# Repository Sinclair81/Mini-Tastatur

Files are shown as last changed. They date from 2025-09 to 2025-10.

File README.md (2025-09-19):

# Mini-Tastatur



<!-- markdownlint-disable MD033 -->
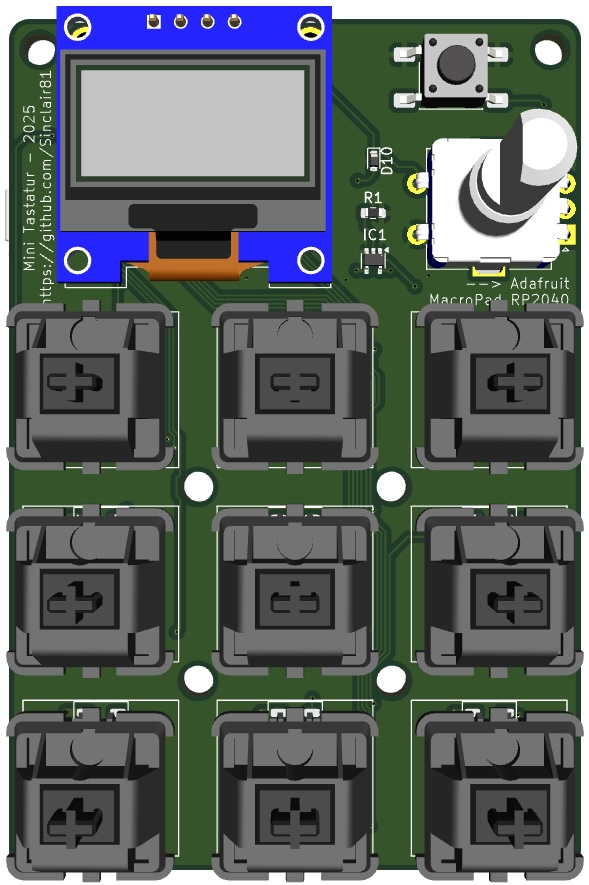
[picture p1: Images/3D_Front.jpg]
3D_Front

<!-- markdownlint-enable MD033 -->

A smal clone of the [Adafruit MacroPad RP2040](https://learn.adafruit.com/adafruit-macropad-rp2040).  

- Raspberry Pi Pico
- I2C Display
- 9 Buttons

[CircuitPython for Raspberry Pi Pico](https://circuitpython.org/board/raspberry_pi_pico)

[MacroPad CircuitPython Library](https://learn.adafruit.com/adafruit-macropad-rp2040/macropad-circuitpython-library)

Extract the zip and navigate to the lib folder found within. Drag the necessary libraries from the zip lib folder to the lib folder on your CIRCUITPY drive.

At a minimum, the following libraries are required to use the MacroPad CircuitPython library. Drag the following files and folders to the lib folder on your CIRCUITPY drive:

adafruit_macropad.mpy - A helper library for using the features of the Adafruit MacroPad.
adafruit_debouncer.mpy - A helper library for debouncing pins. Used to provide a debounced instance of the rotary encoder switch.
adafruit_simple_text_display.mpy - A helper library for easily displaying lines of text on a display.
neopixel.mpy - A CircuitPython driver for NeoPixel LEDs.
adafruit_display_text/ - A library to display text using displayio. Used for the text display functionality of the MacroPad library that allows you easily display lines of text on the built-in display.
adafruit_hid/ - CircuitPython USB HID drivers.
adafruit_midi/ - A CircuitPython helper for encoding/decoding MIDI packets over a MIDI or UART connection
adafruit_ticks.mpy - A helper to work with intervals and deadlines in milliseconds

There is an example included that uses a library that is not required for the MacroPad library to work, but provides a convenient way to layout text in grid. The following library is recommended as well:

adafruit_displayio_layout - A library that includes a grid layout helper.

[MacroPad Basics](https://learn.adafruit.com/adafruit-macropad-rp2040/macropad-basics)  

[MacroPad Display Text](https://learn.adafruit.com/adafruit-macropad-rp2040/macropad-display-text)  

[MacroPad Keyboard and Mouse](https://learn.adafruit.com/adafruit-macropad-rp2040/macropad-keyboard-and-mouse)  

[Arduino IDE Setup](https://learn.adafruit.com/adafruit-macropad-rp2040/arduino-ide-setup)  

[MacroPad Arduino Example](https://learn.adafruit.com/adafruit-macropad-rp2040/arduino)  

Name                  | Pin
--------------------- | ---------------------
Button / Boot select  | GPIO0 / TP6  
Button 1              | GPIO1  
Button 2              | GPIO2  
Button 3              | GPIO3  
Button 4              | GPIO4  
Button 5              | GPIO5  
Button 6              | GPIO6  
Button 7              | GPIO7  
Button 8              | GPIO8  
Button 9              | GPIO9  
Rotary Encoder A      | GPIO17  
Rotary Encoder B      | GPIO18  
Neopixel (9)          | GPIO19  
Display SDA           | GPIO20  
Display SCL           | GPIO21  
Reset                 | RUN

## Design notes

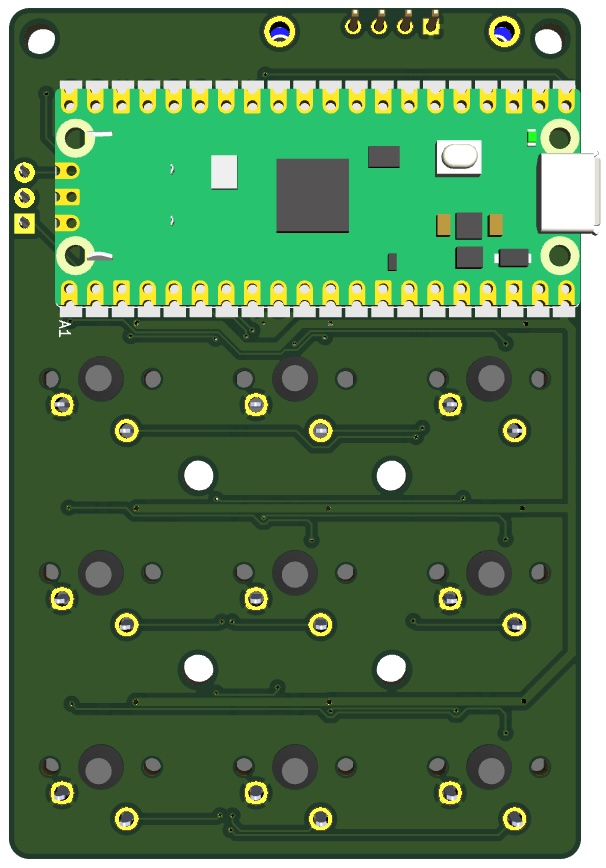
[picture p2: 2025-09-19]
Images/3D_Back.jpg

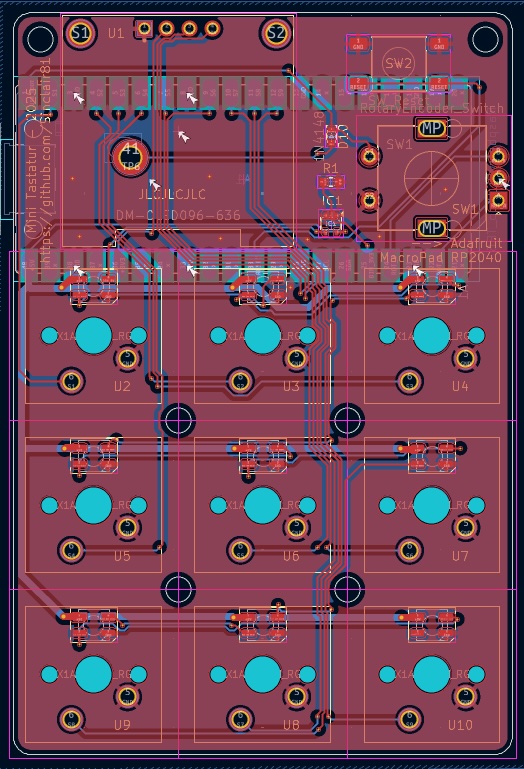
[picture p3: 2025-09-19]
Images/PCB_Front.jpg

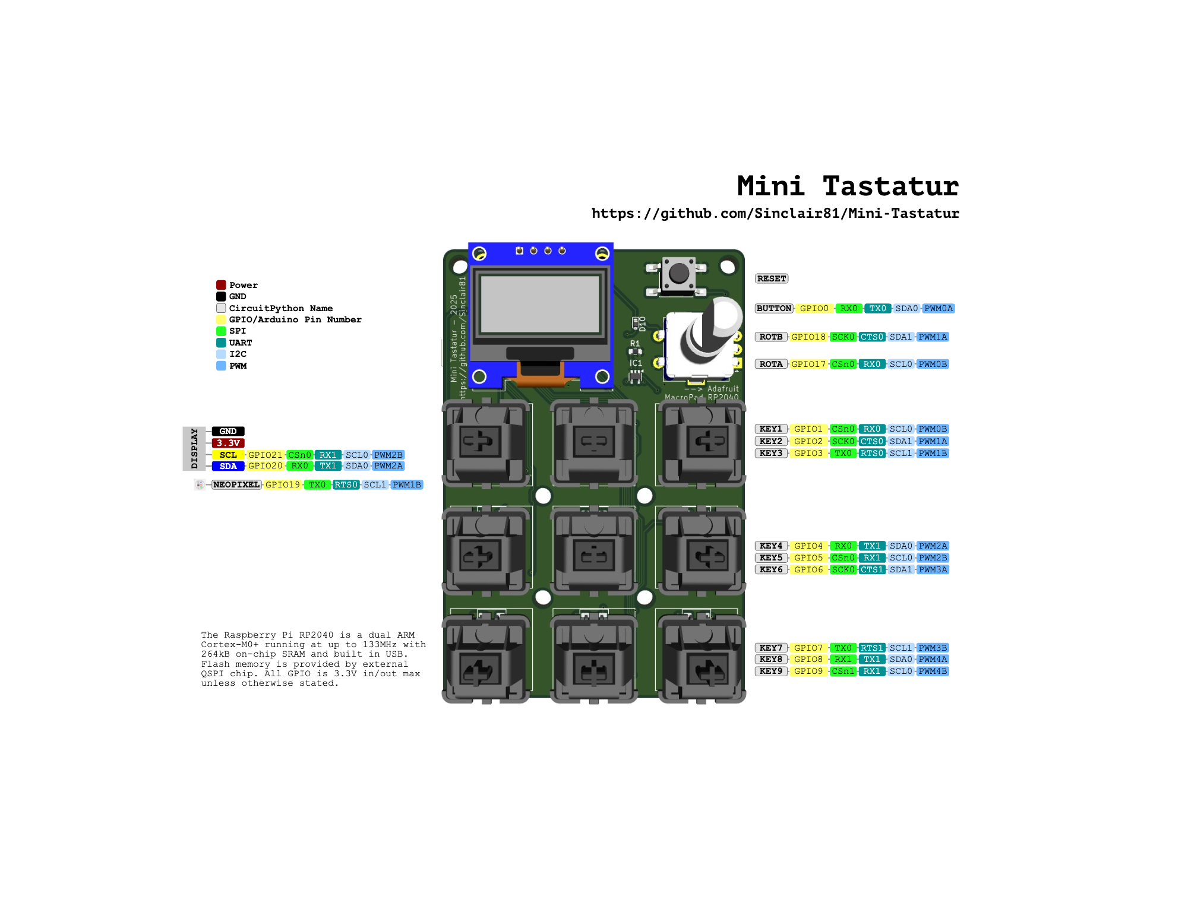
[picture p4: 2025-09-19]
Mini Tastatur Pins.png

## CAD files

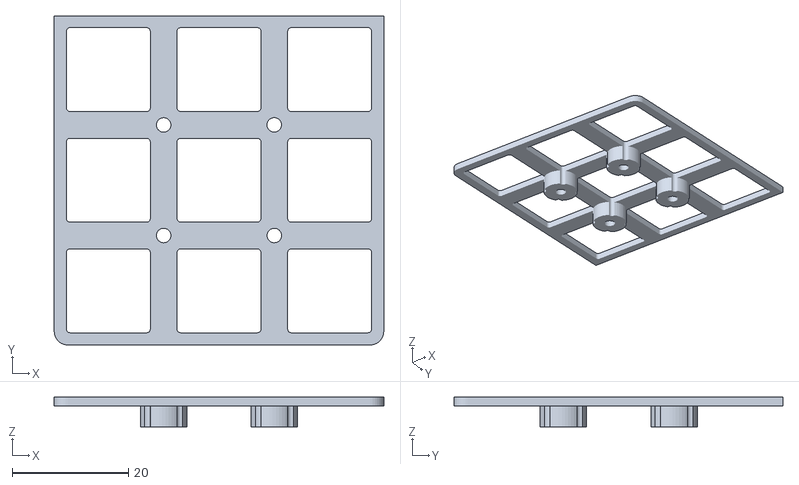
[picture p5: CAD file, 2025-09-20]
3D Print/Mini_Tastatur v14 Key holder.stl
56.6 x 56.5 x 5.10

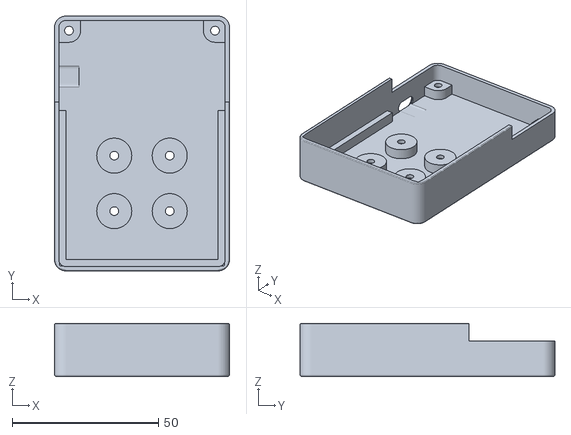
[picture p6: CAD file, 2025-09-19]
3D Print/Mini_Tastatur v14 housing bottom.stl
60.0 x 87.3 x 18.2

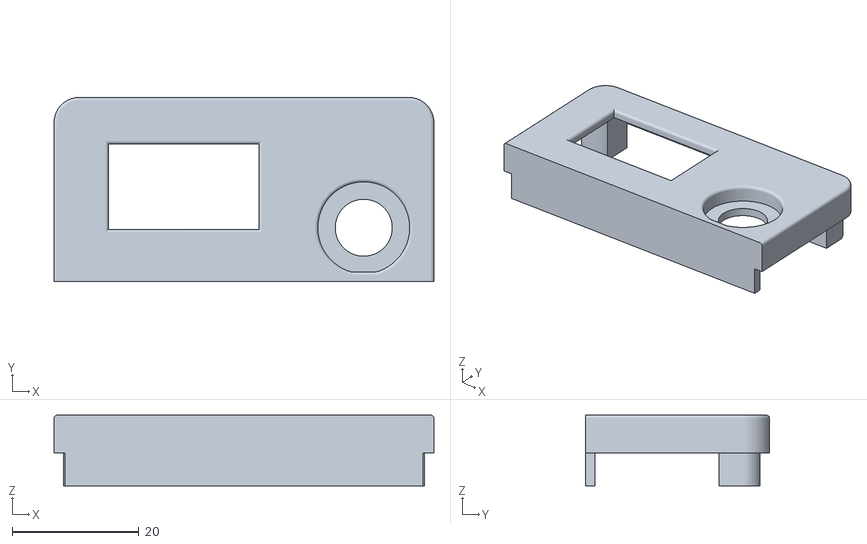
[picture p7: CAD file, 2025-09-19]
3D Print/Mini_Tastatur v14 housing top.stl
60.0 x 29.1 x 11.1

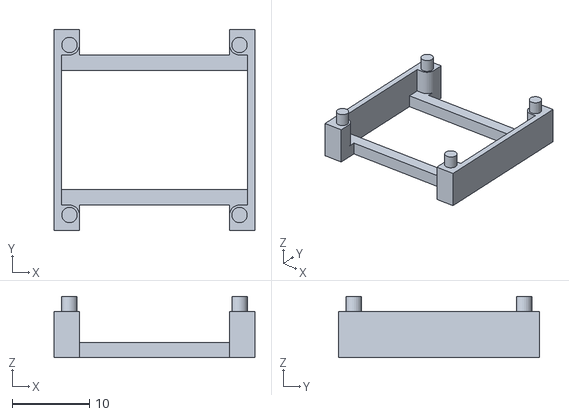
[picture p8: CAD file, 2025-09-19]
3D Print/Mini_Tastatur v13 display holder.stl
26.0 x 26.0 x 7.95

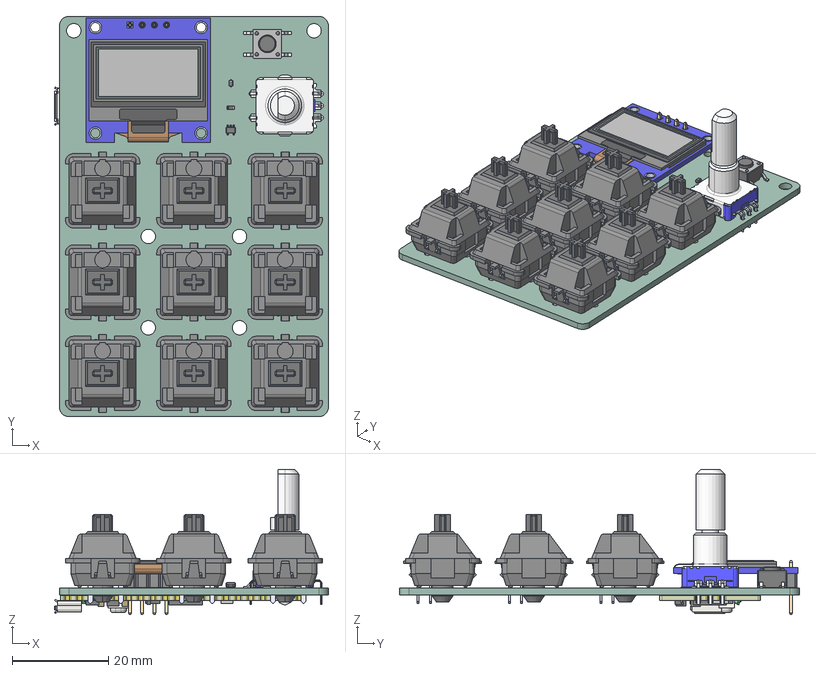
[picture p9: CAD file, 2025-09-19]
3D Print/Mini_Tastatur.step
57.0 x 83.3 x 30.2 mm
MX1A-11NN x 9
SOT-353_SC-70-5
DM-OLED096-636_Module
DM-OLED096-636_Panel
EC11E18244AU
R_0603_1608Metric
D_SOD-523
SW_Push_1P1T_NO_E-Switch_TL3301NxxxxxG
RaspberryPi_Pico_Module_KiCad
Mini_Tastatur_PCB

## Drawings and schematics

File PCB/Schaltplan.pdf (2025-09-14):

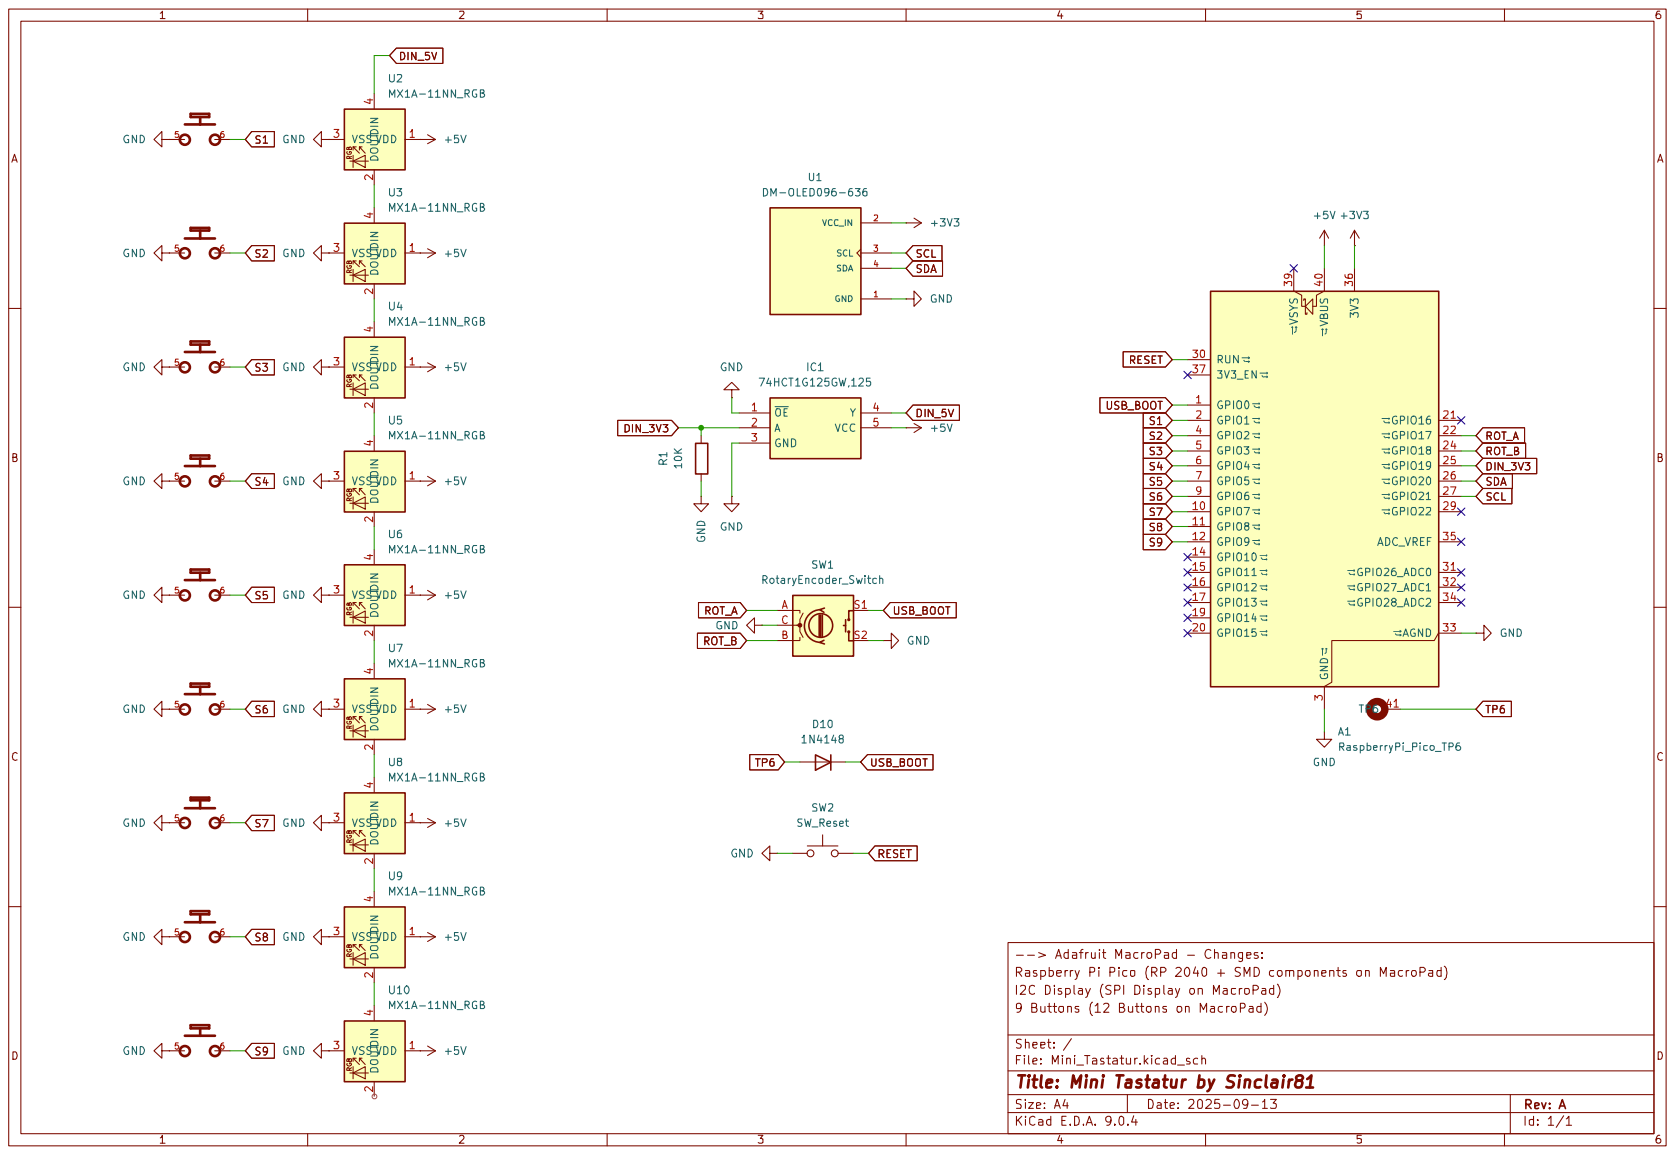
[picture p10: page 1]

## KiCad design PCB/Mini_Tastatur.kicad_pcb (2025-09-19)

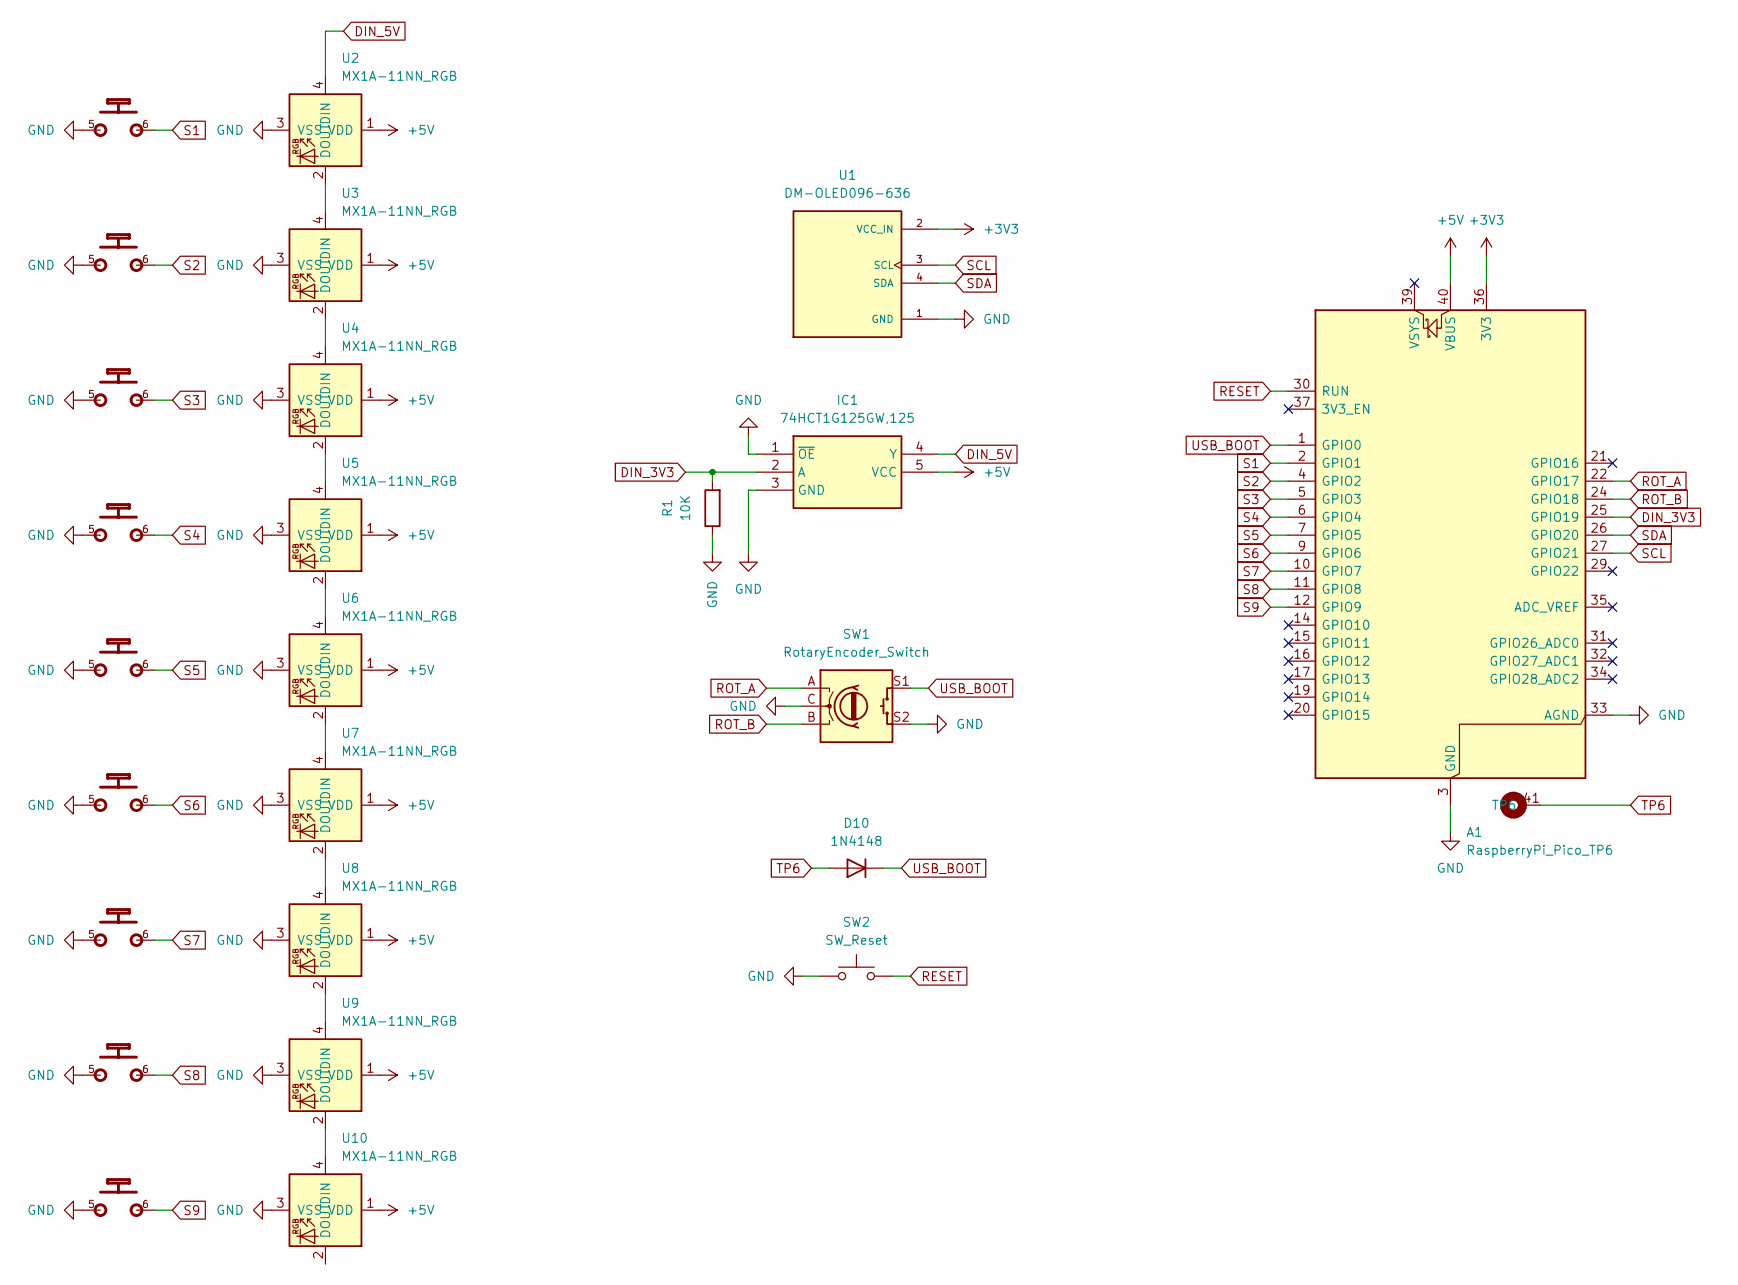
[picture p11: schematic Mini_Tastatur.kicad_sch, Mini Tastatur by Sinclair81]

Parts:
A1: RaspberryPi_Pico_TP6; RaspberryPi_Pico_Common_SMD_TP6
D10: 1N4148; D_SOD-523
IC1: 74HCT1G125GW,125; SOT65P212X110-5N; Mouser Part Number 771-74HCT1G125GW-G
R1: 10K; R_0603_1608Metric
SW1: RotaryEncoder_Switch; RotaryEncoder_Alps_EC11E-Switch_Vertical_H20mm
SW2: SW_Reset; SW_Push_1P1T_NO_E-Switch_TL3301NxxxxxG
U1: DM-OLED096-636; MODULE_DM-OLED096-636; PARTREV 2018-09-10
U2, U3, U4, U5, U6, U7, U8, U9, U10: MX1A-11NN_RGB; CHERRY_MX1A-11NN_SWITCH_RGB

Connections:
+3V3: A1.36 (3V3), U1.2 (VCC_IN)
+5V: A1.40 (VBUS), IC1.5 (VCC), U2.1 (VDD), U3.1 (VDD), U4.1 (VDD), U5.1 (VDD), U6.1 (VDD), U7.1 (VDD), U8.1 (VDD), U9.1 (VDD), U10.1 (VDD)
DIN_3V3: A1.25 (GPIO19), IC1.2 (A), R1.2
DIN_5V: IC1.4 (Y), U2.4 (DIN)
GND: A1.3 (GND), A1.8 (GND), A1.13 (GND), A1.18 (GND), A1.23 (GND), A1.28 (GND), A1.33 (AGND), A1.38 (GND), IC1.1 (~OE), IC1.3 (GND), R1.1, SW1.C, SW1.S2, SW2.1, U1.1 (GND), U2.3 (VSS), U2.5, U3.3 (VSS), U3.5, U4.3 (VSS), U4.5, U5.3 (VSS), U5.5, U6.3 (VSS), U6.5, U7.3 (VSS), U7.5, U8.3 (VSS), U8.5, U9.3 (VSS), U9.5, U10.3 (VSS), U10.5
unnamed: U2.2 (DOUT), U3.4 (DIN)
unnamed: U3.2 (DOUT), U4.4 (DIN)
unnamed: U4.2 (DOUT), U5.4 (DIN)
unnamed: U5.2 (DOUT), U6.4 (DIN)
unnamed: U6.2 (DOUT), U7.4 (DIN)
unnamed: U7.2 (DOUT), U8.4 (DIN)
unnamed: U8.2 (DOUT), U9.4 (DIN)
unnamed: U9.2 (DOUT), U10.4 (DIN)
RESET: A1.30 (RUN), SW2.2
ROT_A: A1.22 (GPIO17), SW1.A
ROT_B: A1.24 (GPIO18), SW1.B
S1: A1.2 (GPIO1), U2.6
S2: A1.4 (GPIO2), U3.6
S3: A1.5 (GPIO3), U4.6
S4: A1.6 (GPIO4), U5.6
S5: A1.7 (GPIO5), U6.6
S6: A1.9 (GPIO6), U7.6
S7: A1.10 (GPIO7), U8.6
S8: A1.11 (GPIO8), U9.6
S9: A1.12 (GPIO9), U10.6
SCL: A1.27 (GPIO21), U1.3 (SCL)
SDA: A1.26 (GPIO20), U1.4 (SDA)
TP6: A1.41 (TP6), D10.2 (A)
USB_BOOT: A1.1 (GPIO0), D10.1 (K), SW1.S1

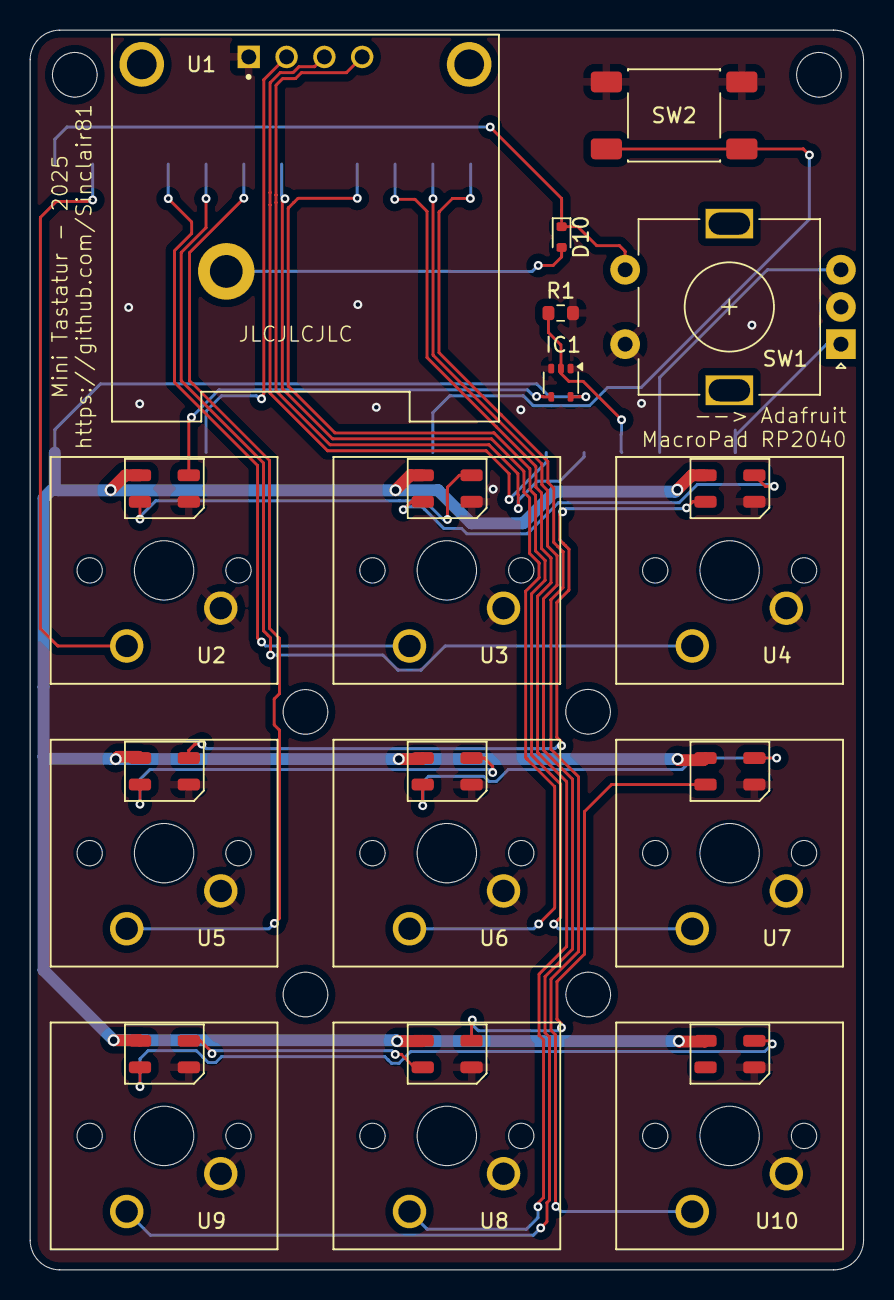
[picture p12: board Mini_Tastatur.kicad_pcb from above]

Board: 2 copper layers, 56.0 x 83.3 mm, 16 parts (1 on the bottom side), 29 nets.

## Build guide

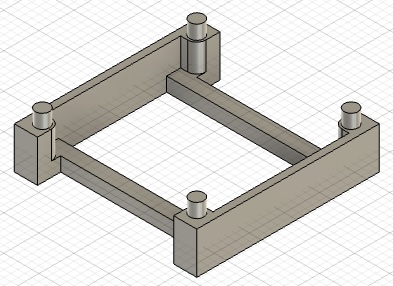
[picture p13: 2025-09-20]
3D Print/Mini_Tastatur v13 display holder.jpg

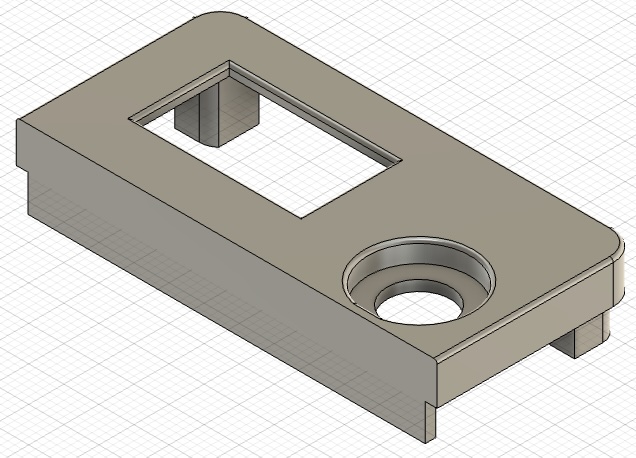
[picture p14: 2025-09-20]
3D Print/Mini_Tastatur v14 housing top.jpg

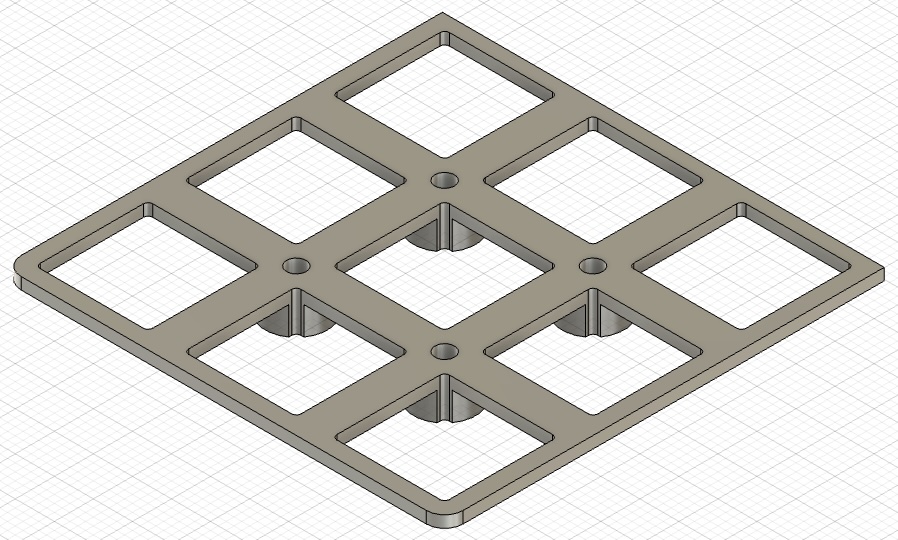
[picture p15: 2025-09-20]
3D Print/Mini_Tastatur v14 Key holder.jpg

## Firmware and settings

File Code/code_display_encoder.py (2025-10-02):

# Kombiniertes Display + Rotary Encoder Script (Raspberry Pi Pico + CircuitPython)
# - SSD1306/SSD1315 I2C-Display @ 0x3C an GP21 (SCL) / GP20 (SDA)
# - Rotary Encoder an GP17 (A) / GP18 (B), divisor=2 (2 Detents pro Zyklus)
# - Optionaler Taster am GP0 (auf GND, interner Pull-Up aktiv)

import time
import board
import busio
import displayio
from i2cdisplaybus import I2CDisplayBus
from adafruit_displayio_ssd1306 import SSD1306
from adafruit_display_text import label
import terminalio

import rotaryio
import digitalio

# --- Display einrichten ---
displayio.release_displays()

# I2C initialisieren (GP21=SCL, GP20=SDA)
i2c = busio.I2C(scl=board.GP21, sda=board.GP20)

# Display-Bus + Display
display_bus = I2CDisplayBus(i2c, device_address=0x3C)
display = SSD1306(display_bus, width=128, height=64)

# Root-Gruppe und Text-Label
splash = displayio.Group()
# Größere Schrift durch scale; Position leicht eingerückt
value_label = label.Label(
    terminalio.FONT,
    text="Encoder: 0",
    color=0xFFFFFF,
    scale=1,
    x=4,    # linke Einrückung
    y=36,   # ungefähr mittig (Baseline)
)
splash.append(value_label)
display.root_group = splash

# --- Encoder + Taster einrichten ---
# divisor=2 wie in deinem Encoder-Snippet (für 2 Detents pro Zyklus)
encoder = rotaryio.IncrementalEncoder(board.GP17, board.GP18, 2)

# Optionaler Button am Encoder (Pull-Up aktiv -> gedrückt == False)
button = digitalio.DigitalInOut(board.GP0)
button.direction = digitalio.Direction.INPUT
button.pull = digitalio.Pull.UP
last_position = None
last_btn_state = True  # True = nicht gedrückt (wegen Pull-Up)

# --- Hauptloop ---
while True:
    # Encoder-Wert lesen
    position = encoder.position

    # Nur bei Änderung das Display-Label aktualisieren (schont I2C und CPU)
    if position != last_position:
        value_label.text = f"Encoder: {position}"
        last_position = position

    # Button-Edge-Detection (optional)
    btn_state = button.value
    if btn_state != last_btn_state:
        if not btn_state:
            # Kurz sichtbar machen, dass Button gedrückt wurde
            value_label.text = f"Encoder: {position} *"
        else:
            # Stern wieder entfernen
            value_label.text = f"Encoder: {position}"
        last_btn_state = btn_state

    time.sleep(0.01)  # kleines Delay zur Entlastung

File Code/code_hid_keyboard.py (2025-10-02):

import time
import board
import keypad
import usb_hid

from adafruit_hid.keyboard import Keyboard
from adafruit_hid.keycode import Keycode

# -----------------------------
# Belegung deiner 9 Tasten
# Reihenfolge: Taste 0..8
# -----------------------------
COMBOS = [
    "^!+A",      # Taste 0: Ctrl+Alt+Shift+A # Mac ok
    "^#+A",      # Taste 1: Ctrl+Win+Shift+A
    "$C",        # Taste 2: Command+C
    "$V",        # Taste 3: Command+V
    "^C",        # Taste 4: Ctrl+C
    "^V",        # Taste 5: Ctrl+V
    "#+[ESC]",   # Taste 6: Win+Shift+Esc
    "!^T",       # Taste 7: Alt+Ctrl+T
    "^[TAB]",    # Taste 8: Ctrl+Tab
    "^+[TAB]",   # Taste .: Ctrl+Shift+Tab
    "#D",        # Taste .: Win+D
    "[F5]",      # Taste .: F5
]

# -----------------------------
# Pins der 9 Tasten (anpassen!)
# value_when_pressed=False + Pull-Up => Taster nach GND
# -----------------------------
KEY_PINS = (board.GP1, board.GP2, board.GP3,
            board.GP4, board.GP5, board.GP6, 
            board.GP7, board.GP8, board.GP9)

# -----------------------------
# Mapping für Modifikatoren
# -----------------------------
MOD_MAP = {
    '^': Keycode.LEFT_CONTROL,
    '+': Keycode.LEFT_SHIFT,
    '!': Keycode.LEFT_ALT,
    '#': Keycode.LEFT_GUI,   # Windows/GUI-Taste
    '$': Keycode.COMMAND,    # Mac Command Taste
}

# -----------------------------
# Mapping für Ziffern
# -----------------------------
DIGIT_MAP = {
    '0': Keycode.ZERO,
    '1': Keycode.ONE,
    '2': Keycode.TWO,
    '3': Keycode.THREE,
    '4': Keycode.FOUR,
    '5': Keycode.FIVE,
    '6': Keycode.SIX,
    '7': Keycode.SEVEN,
    '8': Keycode.EIGHT,
    '9': Keycode.NINE,
}

# -----------------------------
# Mapping für Sondertasten in [KLAMMERN]
# Du kannst hier beliebig erweitern.
# -----------------------------
NAME_MAP = {
    "ESC": Keycode.ESCAPE,
    "ESCAPE": Keycode.ESCAPE,
    "TAB": Keycode.TAB,
    "ENTER": Keycode.ENTER,
    "RETURN": Keycode.ENTER,
    "SPACE": Keycode.SPACEBAR,
    "SPACEBAR": Keycode.SPACEBAR,
    "BACKSPACE": Keycode.BACKSPACE,
    "DELETE": Keycode.DELETE,
    "HOME": Keycode.HOME,
    "END": Keycode.END,
    "PAGEUP": Keycode.PAGE_UP,
    "PAGEDOWN": Keycode.PAGE_DOWN,
    "UP": Keycode.UP_ARROW,
    "DOWN": Keycode.DOWN_ARROW,
    "LEFT": Keycode.LEFT_ARROW,
    "RIGHT": Keycode.RIGHT_ARROW,
    # Funktionstasten:
    "F1": Keycode.F1,  "F2": Keycode.F2,  "F3": Keycode.F3,  "F4": Keycode.F4,
    "F5": Keycode.F5,  "F6": Keycode.F6,  "F7": Keycode.F7,  "F8": Keycode.F8,
    "F9": Keycode.F9,  "F10": Keycode.F10, "F11": Keycode.F11, "F12": Keycode.F12,
}

def parse_combo(combo: str):
    """
    Parsen deiner Syntax in eine Liste Keycodes für Keyboard.send().
    - Modifikatoren: ^ (Ctrl), + (Shift), ! (Alt), # (GUI/Win), $ (Command)
    - Buchstaben/Ziffern direkt (A-Z, 0-9)
    - Sondertasten in eckigen Klammern, z.B. [ESC], [F4], [ENTER]
    """
    codes = []

    i = 0
    n = len(combo)
    while i < n:
        ch = combo[i]

        # Modifikatoren
        if ch in MOD_MAP:
            codes.append(MOD_MAP[ch])
            i += 1
            continue

        # Sondertasten [NAME]
        if ch == '[':
            j = combo.find(']', i + 1)
            if j == -1:
                raise ValueError("Fehlende schließende Klammer in Sondertaste: " + combo)
            name = combo[i+1:j].strip().upper()
            if name not in NAME_MAP:
                raise ValueError(f"Unbekannte Sondertaste [{name}]")
            codes.append(NAME_MAP[name])
            i = j + 1
            continue

        # Buchstaben A-Z
        if 'A' <= ch.upper() <= 'Z' and len(ch) == 1:
            codes.append(getattr(Keycode, ch.upper()))
            i += 1
            continue

        # Ziffern 0-9
        if ch in DIGIT_MAP:
            codes.append(DIGIT_MAP[ch])
            i += 1
            continue

        # Leerzeichen ignorieren (optional)
        if ch in (' ', '\t'):
            i += 1
            continue

        # Falls etwas nicht gemappt ist:
        raise ValueError(f"Nicht unterstütztes Zeichen in Combo: {ch!r}")

    # Duplikate entfernen (z. B. doppelt gesetzte Modifikatoren), Reihenfolge beibehalten
    seen = set()
    deduped = []
    for c in codes:
        if c not in seen:
            deduped.append(c)
            seen.add(c)
    return tuple(deduped)

# ---------- HID & Keypad initialisieren ----------
kbd = Keyboard(usb_hid.devices)
time.sleep(0.8)  # kurze Wartezeit, bis Host das HID-Device erkennt

keys = keypad.Keys(KEY_PINS, value_when_pressed=False, pull=True)

print("Bereit. 9 Tasten -> sendet definierte Tastenkombinationen.")

# ---------- Event-Loop ----------
while True:
    event = keys.events.get()
    if event:
        if event.pressed:
            key_no = event.key_number
            try:
                combo = COMBOS[key_no]
                codes = parse_combo(combo)
                # EINMALIGER "Tap" der gesamten Akkord-Kombination:
                kbd.send(*codes)
                # Falls du Modifikatoren HALTEN willst, statt send(): siehe unten.
                # kbd.press(*modifier_codes); kbd.send(non_modifier); kbd.release_all()
                # (hier nicht nötig – send() macht Tap für alle auf einmal)
                # Debug:
                # print(f"Taste {key_no} -> {combo} -> {codes}")
                #
                # Der Stern * in kbd.send(*codes) bedeutet in Python Argument‑Unpacking (Auspacken von Argumenten).
            except Exception as e:
                # Fehler sichtbar machen, blockiert aber die Schleife nicht
                print("Fehler bei Taste", key_no, "Combo:", COMBOS[key_no], "->", e)
        # released ignorieren (kein Auto-Repeat)
    # kleines sleep optional, um CPU zu sparen
    time.sleep(0.001)

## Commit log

2025-09-19 3d print
    [Mini_Tastatur v13_Key_holder.stl, Mini_Tastatur v13_display_holder.stl, Mini_Tastatur v13_housing_bottom.stl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]
2025-09-20 STL v14
    [Mini_Tastatur v13 display holder.stl, Mini_Tastatur v13_Key_holder.stl, Mini_Tastatur v14 Key holder.stl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]
2025-09-20 STL Images
